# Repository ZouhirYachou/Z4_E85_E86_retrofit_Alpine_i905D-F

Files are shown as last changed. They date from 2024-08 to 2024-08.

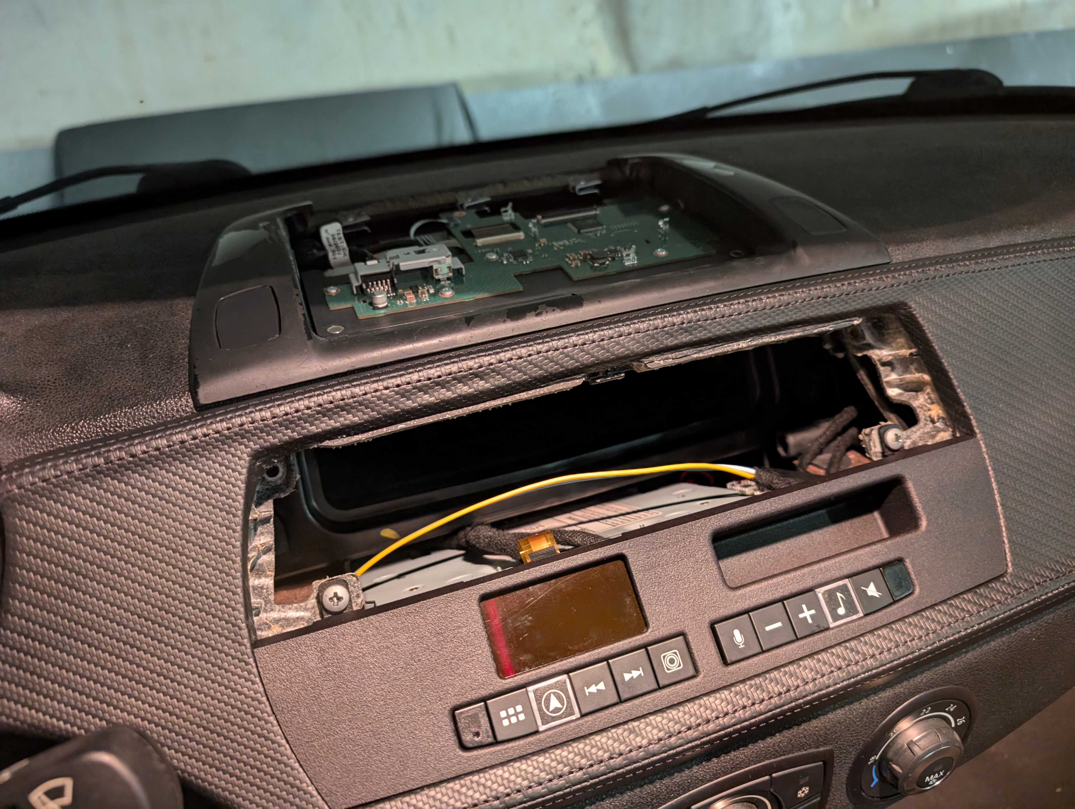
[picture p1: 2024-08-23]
images/PXL_20240823_183641267.jpg

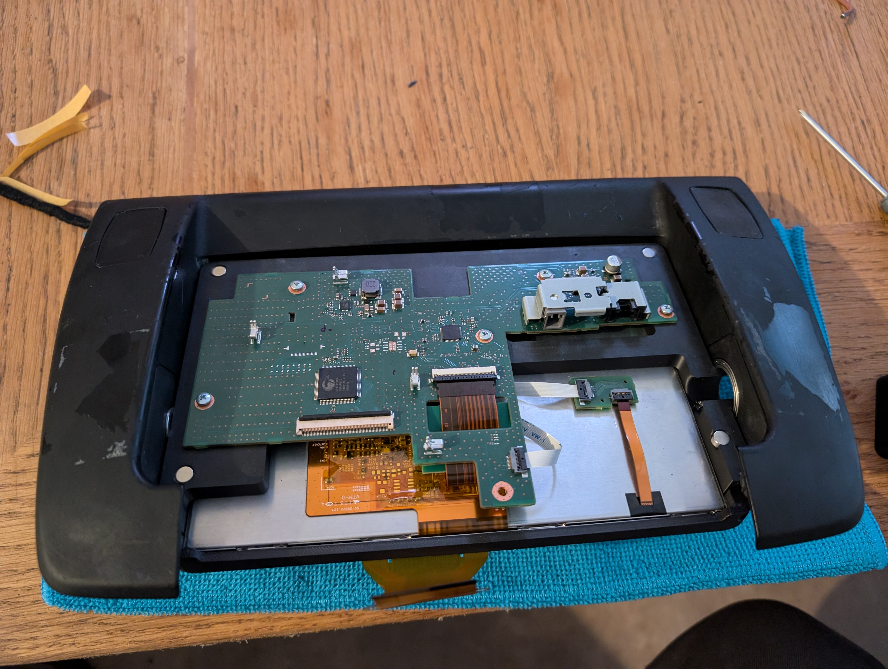
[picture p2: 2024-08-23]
images/PXL_20240809_151102933.jpg

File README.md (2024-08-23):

# Z4_E85_E86_retrofit_Alpine_i905D-F
This project is meant to document the retrofit of the Alpine_i905D-F stereo in a Z4 E85 E86 with existing CID

## The Display
The Alpine kit is provided with a 9 inches display with touchscreen in its casing, the provided display does not fit in the orignal outer case of the Z4 E85 CID, therefore, I'm using a 8 inches display sourced on Aliexpress

After a 3D scan of the outer case of the CID, I designed 3D parts while trying to keep the original shapes of the CID. See images

This involves the dissasembly of the 9 inches display in the Alpine kit to retreive the control PCB. Below are the parts needed for this first point

- 8 inches display: C080EAN01.0 (Same manufacturer and resolution as the 9 inches display)
- Alpine kit: https://www.alpine-electronics.fr/p/Products/freestyle-9-inch-navigation-system/i905d-f
- CID (Central information display) BMW Z4 E85/E86 part number: 65509169175
- 40 pins extension PCB (see PCBs)
- 3D printed parts (see STLs)
- The touchscreen function of the screen has not been addressed (need to do some reverse engineering to make it work with a smaller touchscreen)

## Stereo Fascia
Same as the above, the original part has been scanned and designed a custom fascia for the Alpine stereo buttons and the Gauge.S implementation (https://github.com/handmade0octopus/gauge.s-sorek.uk)

See images, this part has been printed in SLS but can be printed in FDM if splited in the middle

## PCB extension 26 Pins from the instrument cluster
This PCB with its soldered parts allows me to run the Gauge S and grab the T15 and T30 (Ignition Signal and Permanent 12V) from the car to power the other PCB meant to control the stepper motor

## PCB stepper motor control
This PCB with an Arduino Uno and a stepper driver A4988, mimics the original behavior
- Ignition ON = Opens the display
- Ignition OFF = Closes the display
- Original buttons to control the display have not been implemented yet

## To do list
- A working Touchscreen
- Improve the pivot mecanism (too much play and uses a belt from the motor to be driven)
- Reduce the noise of the stepper motor (nema 17 with a 10:1 gearbox)
- Add support for the original buttons
- Documentation (Complete BOM, how to print and assemble)

## Video of the current status in the car

Watch the video (https://youtu.be/eJ5ha1z3iYY)

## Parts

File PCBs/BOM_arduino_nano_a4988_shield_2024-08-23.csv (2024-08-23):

ID | Name | Designator | Footprint | Quantity | Manufacturer Part | Manufacturer | Supplier | Supplier Part | Price
1 | CONN-TH_3P-P5.00_MAX_MX126-5.0-GN01-03P-CU-S-A | U9 | CONN-TH_3P-P5.00_MAX_MX126-5.0-GN01-03P-CU-S-A | 1 | MX126-5.0-GN01-03P-Cu-S-A | MAX(迈旭) | LCSC | C5188435 | 0.083
2 | CONN-TH_2P-P5.00_MX126-5.0-GN01-02P-CU-S-A | U8 | CONN-TH_2P-P5.00_MX126-5.0-GN01-02P-CU-S-A | 1 | MX126-5.0-GN01-02P-Cu-S-A | MAX(迈旭) | LCSC | C5188434 | 0.055
3 | CONN-TH_6P-P1.25_HX-1.25MM-6P-ZZ-MS | U7 | CONN-TH_6P-P1.25_HX-1.25MM-6P-ZZ-MS | 1 | 1.25mm-6P ZZ-MS | SHOU HAN(首韩) | LCSC | C5368709 | 0.03
4 | CONN-TH_3P-P2.50_HX-2.54MM-3P-WZ | U3 | CONN-TH_3P-P2.50_HX-2.54MM-3P-WZ | 1 | HX 2.54mm-3P WZ | hanxia(韩下) | LCSC | C7543445 | 0.011
5 | CONN-TH_4P-P2.50_HX-2.54MM-4P-WZ | U5 | CONN-TH_4P-P2.50_HX-2.54MM-4P-WZ | 1 | HX 2.54mm-4P WZ | hanxia(韩下) | LCSC | C7543446 | 0.014
6 | CAP-TH_BD6.3-P2.50-D0.6-FD-1 | U1 | CAP-TH_BD6.3-P2.50-D0.6-FD-1 | 1 | KNE2100UF25V149EC0011 | KNSCHA(科尼盛) | LCSC | C2927892 | 0.113
7 | CONN-TH_C3030WR-F-2X02P | U4 | CONN-TH_C3030WR-F-2X02P | 1 | C3030WR-F-2X02P | HR(灿达) | LCSC | C477045 | 0.288
8 | COMM-TH_ARDUINO_NANO | U16 | COMM-TH_ARDUINO_NANO | 1 | ARDUINO_NANO | null | LCSC | C9900017879
9 | _ | ADRIVU1 | A4988 STEPPER MOTOR DRIVER CARRIER COPY | 1

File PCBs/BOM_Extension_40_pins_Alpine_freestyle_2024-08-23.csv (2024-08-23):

ID | Name | Designator | Footprint | Quantity | Manufacturer Part | Manufacturer | Supplier | Supplier Part | Price
1 | FH52-40S-0.5SH | U1,U2 | CONN-SMD_FH52-40S-0.5SH | 2 | FH52-40S-0.5SH | HRS(广濑) | LCSC | C2841889 | 0.449

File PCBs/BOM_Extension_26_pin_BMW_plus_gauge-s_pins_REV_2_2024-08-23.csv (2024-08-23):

ID | Name | Designator | Footprint | Quantity | Manufacturer Part | Manufacturer | Supplier | Supplier Part | Price
1 | CONN-TH_ZH1.5-5AW_C2829750 | U2 | CONN-TH_ZH1.5-5AW_C2829750 | 1
2 | CONN-TH_24P-P3.00_HC-MX3.0-2X12A | U11 | CONN-TH_24P-P3.00_HC-MX3.0-2X12A | 1
3 | CONN-TH_C3030WR-F-2X02P | U4 | CONN-TH_C3030WR-F-2X02P | 1 | C3030WR-F-2X02P | HR(灿达) | LCSC | C477045 | 0.288
4 | CONN-TH_185226-2 | U1 | CONN-TH_185226-2 | 1 | 185226-2 | TE Connectivity(泰科电子) | LCSC | C5172903 | 1.063

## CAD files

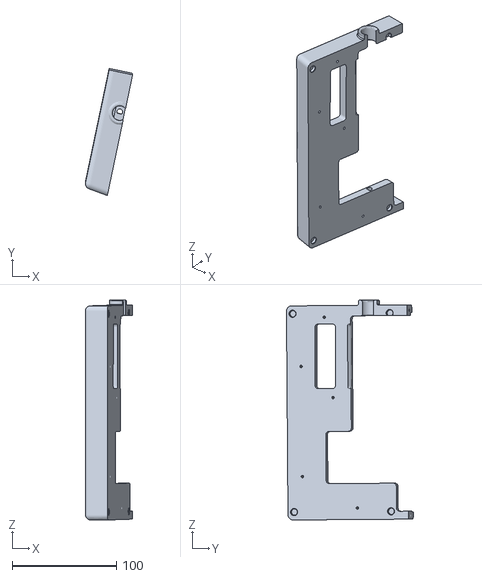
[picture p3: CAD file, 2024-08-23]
STLs/Retrofit_CID_custom_8_inches_Alpine_i905D-F/Main_case_8_inches_display_PCB_control.stl
45.3 x 121.8 x 210.8

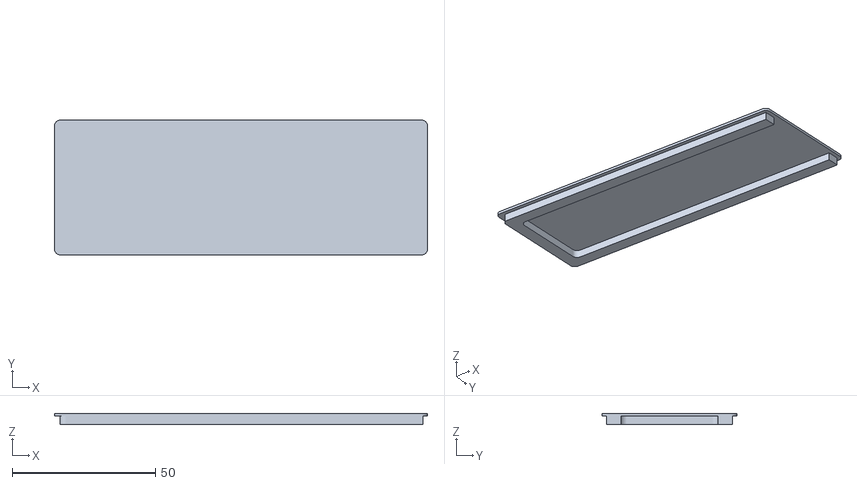
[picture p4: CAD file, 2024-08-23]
STLs/Case_stepper_motor_control/Cover_case_stepper_motor_control.stl
130.0 x 47.0 x 4.00

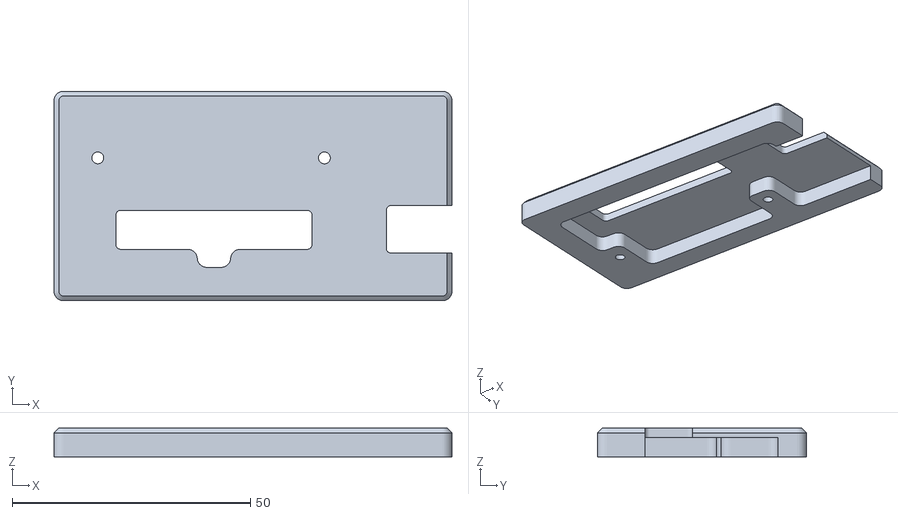
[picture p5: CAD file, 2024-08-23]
STLs/Casing_26_pins_IC_extension/Top_case_26_pins_IC_E85_E86_extension.stl
83.6 x 44.0 x 6.00

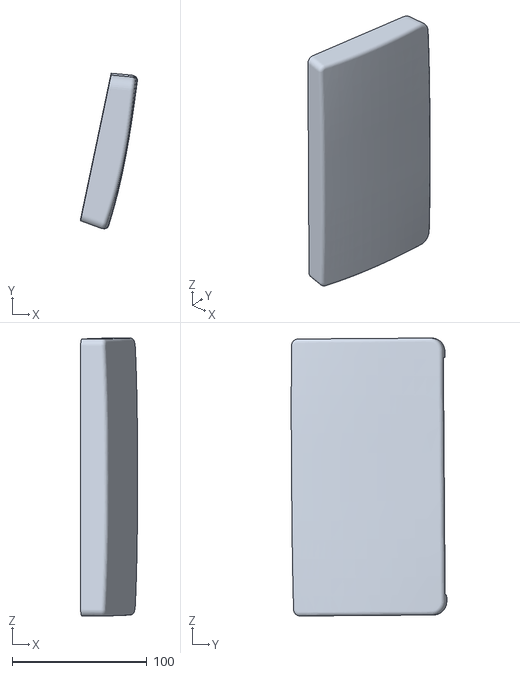
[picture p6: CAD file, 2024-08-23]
STLs/Retrofit_CID_custom_8_inches_Alpine_i905D-F/Top_PCB_control_cover.stl
42.1 x 115.3 x 205.9

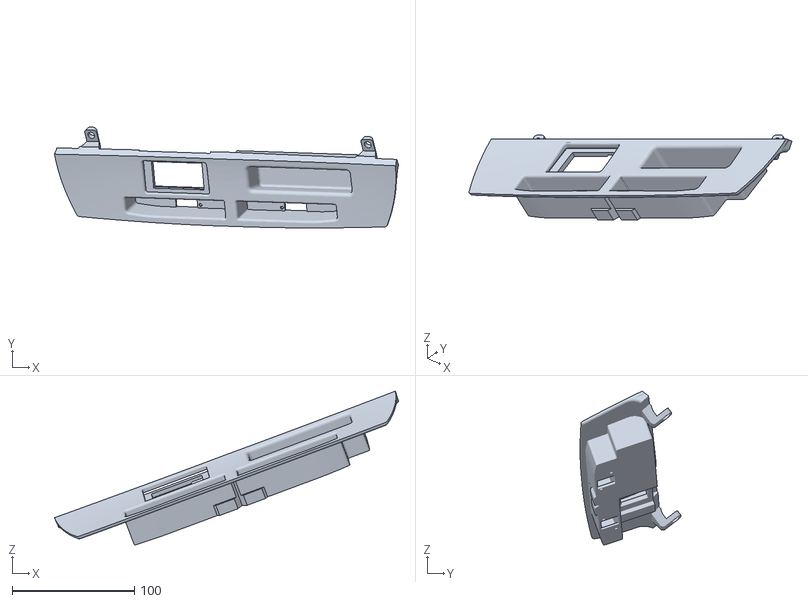
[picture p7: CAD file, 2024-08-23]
STLs/Stereo_fascia/Stereo_fascia_Z4_E85_E86_Alpine_Freestyle_i905D-F_plus_Gauge_S.stl
281.0 x 82.4 x 125.6

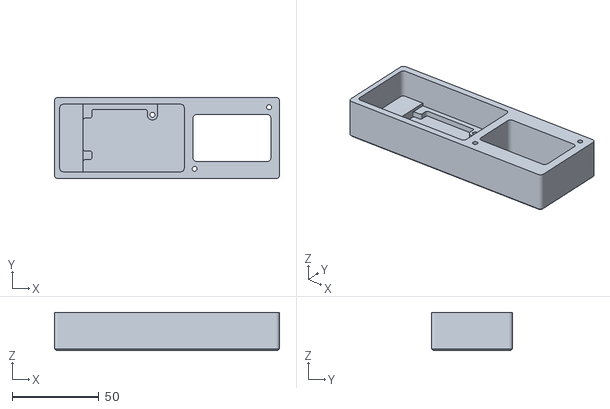
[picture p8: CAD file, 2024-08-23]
STLs/Case_stepper_motor_control/Bottom_case_stepper_motor_control.stl
130.0 x 47.0 x 22.0

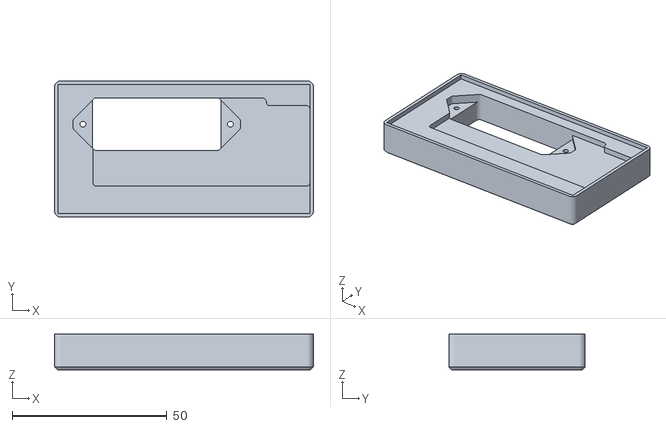
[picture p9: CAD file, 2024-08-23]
STLs/Casing_26_pins_IC_extension/Bottom_case_26_pins_IC_E85_E86_extension.stl
83.6 x 44.0 x 11.6

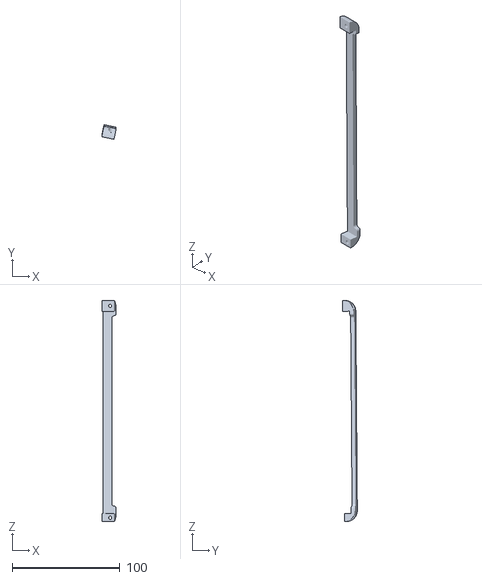
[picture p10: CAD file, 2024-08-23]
STLs/Retrofit_CID_custom_8_inches_Alpine_i905D-F/Bottom_case_8_inches_display_support.stl
13.4 x 13.6 x 205.2

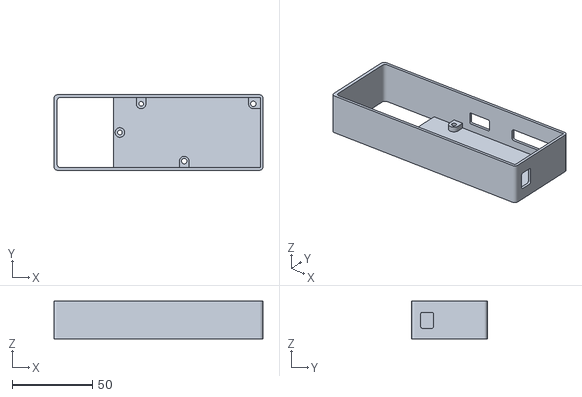
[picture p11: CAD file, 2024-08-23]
STLs/Case_stepper_motor_control/Top_case_stepper_motor_control.stl
130.0 x 47.0 x 23.6

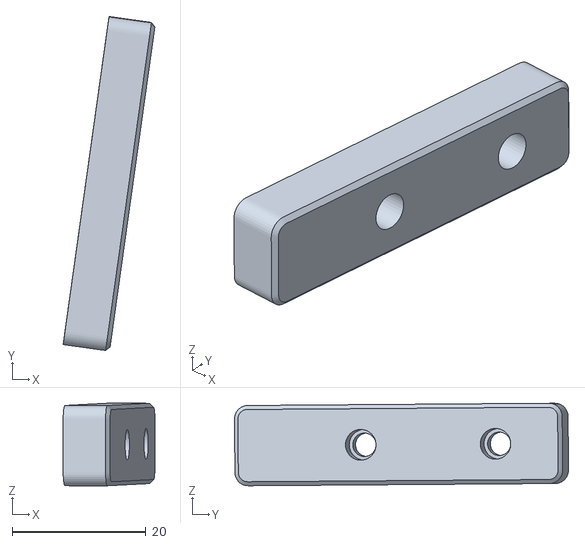
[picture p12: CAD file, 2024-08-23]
STLs/Retrofit_CID_custom_8_inches_Alpine_i905D-F/Anchor_m3_brass_inserts.stl
13.7 x 49.9 x 12.3

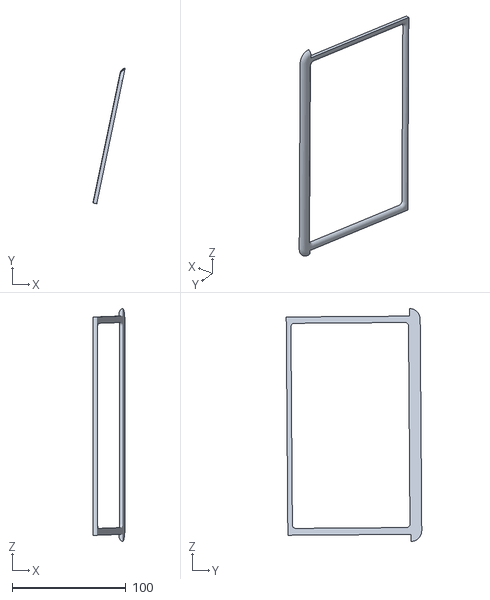
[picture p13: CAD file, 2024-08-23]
STLs/Retrofit_CID_custom_8_inches_Alpine_i905D-F/Front_Bezel_8_inches_display.stl
27.8 x 119.0 x 204.5

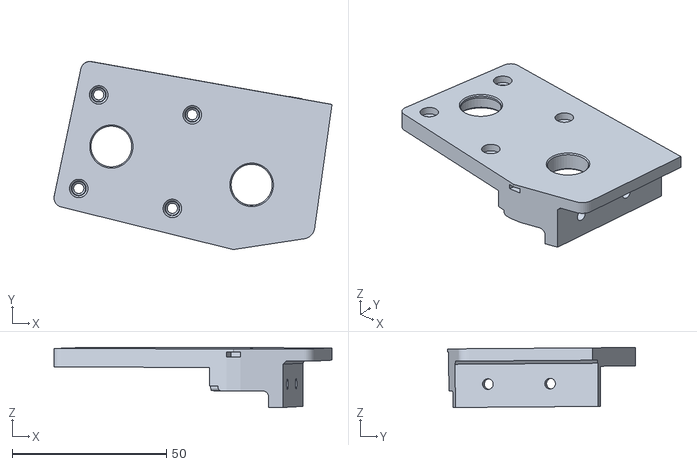
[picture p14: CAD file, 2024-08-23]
STLs/Retrofit_CID_custom_8_inches_Alpine_i905D-F/Holder_pivot_display_right.stl
90.1 x 60.9 x 19.4

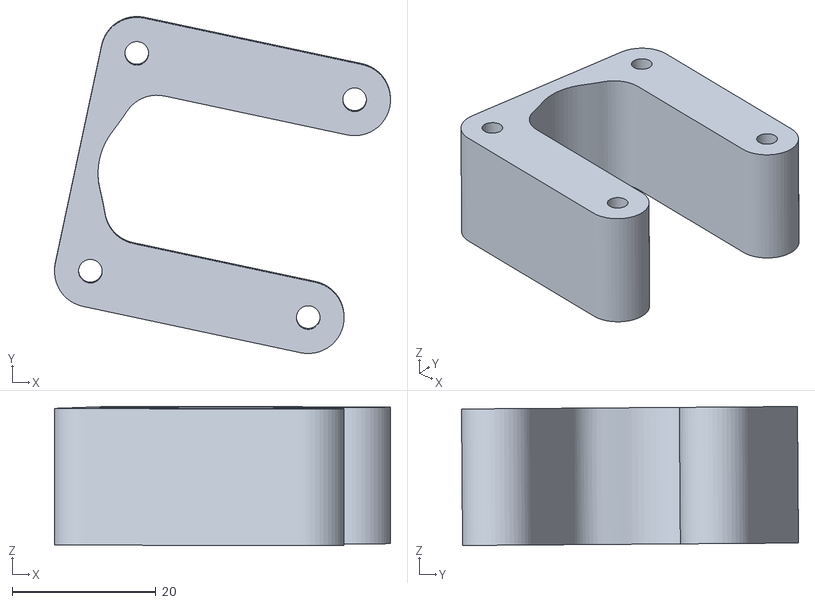
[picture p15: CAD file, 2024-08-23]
STLs/Retrofit_CID_custom_8_inches_Alpine_i905D-F/Spacer_19_mm_stepper_motor.stl
46.8 x 46.9 x 19.3

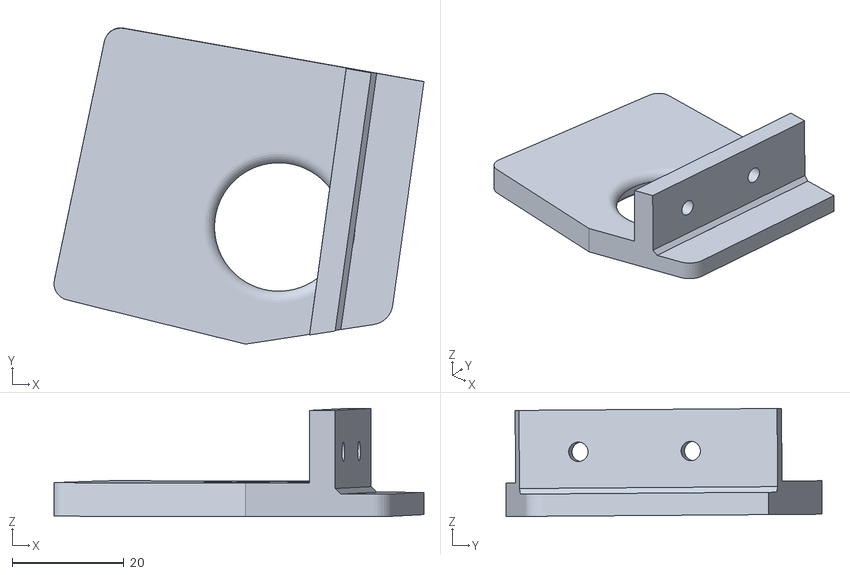
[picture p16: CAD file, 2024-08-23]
STLs/Retrofit_CID_custom_8_inches_Alpine_i905D-F/Holder_pivot_display_left.stl
66.3 x 56.7 x 19.4

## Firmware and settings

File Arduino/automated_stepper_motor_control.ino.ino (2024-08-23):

#include <Arduino.h>
#include "A4988.h"

#define MOTOR_STEPS 200
#define HALL 9
#define IGN 10
#define DIR 11
#define STEP 12

int ignPinState = LOW;
int dispPinState = LOW;  

A4988 stepper(MOTOR_STEPS, DIR, STEP);

void setup() {
    delay(1000);
    stepper.begin(80, 1);
    stepper.enable();
    Serial.begin(9600);
    pinMode(IGN, INPUT);
    pinMode(HALL, INPUT);

    ignPinState = digitalRead(IGN);
    dispPinState = digitalRead(HALL);

    if (ignPinState == HIGH && dispPinState == LOW) 
    {
      delay(1000);
      openDisplay();
    }
}

void loop() { 
  ignPinState = digitalRead(IGN);
  dispPinState = digitalRead(HALL);

  if (ignPinState == LOW && dispPinState == HIGH) 
  {
    delay(2000);
    closeDisplay();
  }
}

void openDisplay() {
  stepper.move(650);
}

void closeDisplay() {
  stepper.move(-650);
}
